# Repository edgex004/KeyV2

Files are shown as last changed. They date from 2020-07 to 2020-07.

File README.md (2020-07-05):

Note: this branch contains modifications in order to generate LP (Choc) keycaps for the Lily58 keyboard.

# Parametric Mechanical Keycap Library

a slightly askew welcome picture

This library is a keycap and keyset construction library for mechanical keyboards, written in openSCAD.

Relevant links:
* Thingiverse: https://www.thingiverse.com/thing:2783650
* Shapeways: https://www.shapeways.com/designer/rsheldiii/creations
* Buy me a coffee: https://ko-fi.com/rsheldiii, but only if you want to!

## How to run

#### OpenSCAD Proper (recommended way)

If you are technically inclined at all, this is definitely the best way to run the code. It's not very hard!

First, you'll need OpenSCAD: http://www.openscad.org/downloads.html. I highly recommend installing the development snapshot, as they generally support more features and are relatively stable. Development snapshots are listed in their own section on the downloads page.

After you have openSCAD installed, you need to download the code and run it. running `git clone https://github.com/rsheldiii/openSCAD-projects.git` if you have git, or downloading [this zip](https://github.com/rsheldiii/openSCAD-projects/archive/master.zip) and extracting the directory should do it. Then all you need to do is open `keys.scad` with openSCAD and you are set! It is possible to edit this project with an external editor by checking off Design => 'Automatic Reload and Preview' in OpenSCAD.

All examples below assume you are running the library on your computer with OpenSCAD.

#### OpenSCAD Customizer

If you're not technically inclined enough to start programming in OpenSCAD (it's easier than you think), you can look into [getting OpenSCAD's customizer working](https://github.com/rsheldiii/KeyV2/wiki/Getting-the-OpenSCAD-Customizer-working).

`customizer.scad` is auto-generated from the other files in this repository due to a quirk with how OpenSCAD shows customizer settings. It should be perpetually kept up to date, but there may be some bugs. feel free to open an issue if you find one!

#### Thingiverse Customizer

The easiest and buggiest way to run this program is to boot it up in [Thingiverse's Customizer](https://www.thingiverse.com/apps/customizer/run?thing_id=2783650). Explanations of each option are provided, as well as some default variables. Twiddle the variables to see how the keycap changes!

Unfortunately I don't think I can update the Thingiverse customizer without breaking it, so you don't get all the cool new features I've been developing over the past couple years.

## High-level overview

This library supports Cherry and Alps switches, and has pre-defined key profiles for SA, DSA, DCS, G20, Hi-Pro and (some form of) OEM keycaps. `keys.scad` is the entry point for everything but the most technical use. Pre-programmed key profiles can be found in the `key_profiles` directory.

Every key starts with default settings (provided in `settings.scad`) that are overridden by each function call. The simplest key you can make would be:

```
key();
```
a bog-standard cherry key

which is a bog-standard DCS row 5 (number / function row) keycap. To change how the key is generated, you can modify the settings directly or add predefined modifier functions like so:

```
// directly modified setting
$stem_inset = 1;
// settings changed through modifier function
sa_row(2) 2u() key();
```

You can chain as many modifier functions as you like!

a 2 unit SA row 2 cherry key

## Modifier functions

There is a bevy of supporting functions to customize your keycaps. You can add a brim to more easily print the stem with `brimmed_stem_support`, make 2x2 keycaps with `2u() 2uh()`, add legends, rotate stems, and more. All these functions manipulate the settings available to you in [`settings.scad`](https://github.com/rsheldiii/KeyV2/blob/master/src/settings.scad), though [some of them](https://github.com/rsheldiii/KeyV2/blob/master/src/key_transformations.scad#L128) are quite complex.

These modifier functions can be found in [`key_profiles/`](https://github.com/rsheldiii/KeyV2/blob/master/src/key_profiles) for different keycap profiles, [`key_types.scad`](https://github.com/rsheldiii/KeyV2/blob/master/src/key_types.scad) for predefined settings for common keys (spacebar, left shift, etc), [`key_sizes.scad`](https://github.com/rsheldiii/KeyV2/blob/master/src/key_sizes.scad) for common unit sizes, and [`key_transformations.scad`](https://github.com/rsheldiii/KeyV2/blob/master/src/key_transformations.scad) for everything else. I encourage you to do some sleuthing but for a list of (most) helper functions with explanations, [Check out the wiki!](https://github.com/rsheldiii/KeyV2/wiki/KeyV2-Helper-Documentation)

These modifier functions may not cover every use case; in that case, you may have to write some SCAD yourself.

## Layouts

new to the library and still in a beta state, layouts allows you to generate an entire layout for a keyboard!

It is recommended to use tined stem support and set `$extra_long_stem_support = true` if you plan on printing these keycaps.

```
60_percent_default("dcs") key();
```

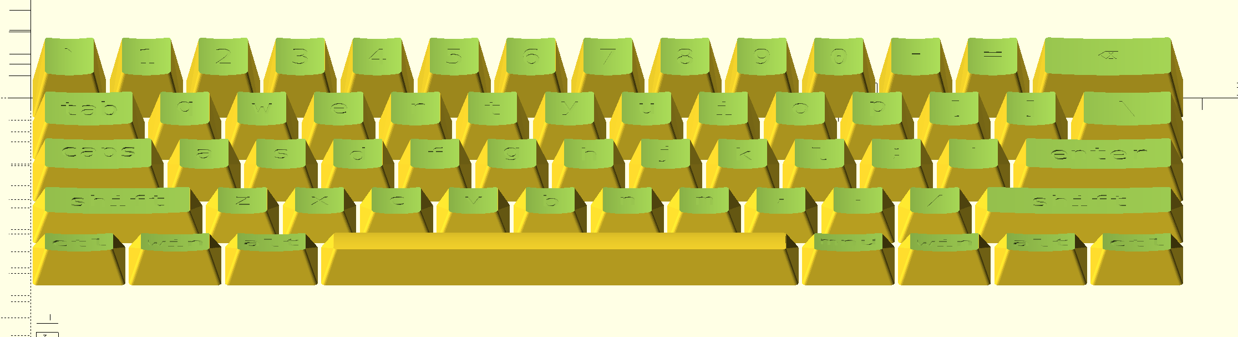
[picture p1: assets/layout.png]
a standard 60 percent layout


layouts accept children, so you can use them as a chained function like other modifiers. Be wary of accidentally overriding something the layout does for you though.

#### Example customizations

Let's say you wanted to generate some 2u stabilized keycaps for an Ergodox, you could do something like this:

```
legends = ["Enter", "Escape", "Tab", "Shift"];
for(y=[0:3]) {
  translate_u(0,y) 2u() dsa_row() stabilized() cherry() legend(legends[y], [0,0, 6]) key();
}
```

a set of 2 unit keys with legends

The `key()` function also supports children, and will place them in the center of the top of the keycap, if you want to quickly design your own artisan keycaps:

```
cherry() key() {
  translate([-6.25,2.3,-0]) scale(0.074) import("Assieme1.stl");
};
```

an artisan key with no-face on it

(no face courtesy of [this thing](https://www.thingiverse.com/thing:519727/))

Artisan support also supports _subtracting_ children by doing `key(inset=true) { ... }`, which is super helpful if you want to make keycaps with legends that are not text. The children will be placed just above the middle of the dish as per usual; you will need to translate them downwards (`ex translate([0,0,-1])`) to get them to 'dig in' to the top of the key.

## Tips and tricks

Looking for information or something specific? you could try checking out the [tips and tricks](TIPS_AND_TRICKS.md) section, or the [examples](/examples) directory.

## What if I want to get _really_ technical?

Now we're talkin!

At the base level this project should function well as an intensive key profile design library. by loading up `src/key.scad` (notice no s) you can tweak variables in `src/settings.scad` to prototype your own profiles. `key.scad` There are currently ~~44~~ a lot of different settings to tweak in `src/settings.scad` including width height and depth of the keycap, dish tilt, top skew, fonts, wall thickness, etc. If you want to see the full list of settings, feel free to browse the file itself: [settings.scad](https://github.com/rsheldiii/KeyV2/blob/master/src/settings.scad) it has lots of comments to help you get started.

This library should also be abstract enough to handle new dish types, keystems, key layouts, key profiles, and key shapes, in case you want to design your own Typewriter-style keycaps, support buckling spring keyboards or design some kind of triangular dished profile. `src/shapes.scad` `src/stems.scad` and `src/dishes.scad` all have a 'selector' module that should allow you to implement your own creations alongside what already exists in their constituent folders.

If you're interested in this, it may help to read the [Technical Design of a keycap](https://github.com/rsheldiii/KeyV2/wiki/Technical-Design-of-a-Keycap) wiki page.

Here's an example of tweaking the settings and code to make a 'stop sign' key profile:

In `key_shape()` in `shapes.scad`:

```
 else if ($key_shape_type == "stop_sign") {
   stop_sign_shape(size, delta, progress);
 }
```

in `src/shapes/stop_sign.scad`:

```
module stop_sign_shape(size, delta, progress){
  rotate([0,0,22.5]) circle(d=size[0] - delta[0], $fn=8);
}
```

In `keys.scad`:

```
union() {
  // make the font smaller
  $font_size = 3;
  // top of keycap is the same size as the bottom
  $width_difference = 0;
  $height_difference = 0;
  $key_shape_type="stop_sign";
  $dish_type = "cylindrical";
  // some keycap tops are slid backwards a little, and we don't want that
  $top_skew = 0;

  legends = ["Stop..", "Hammer", "time!"];

  for(x=[0:len(legends)-1]) {
    translate_u(x) cherry() key(legends[x]);
  }
}
```

three stop-sign shaped keys with legends

## Printing Help

Prints from this library are still challenging, despite all efforts to the contrary. Resin printers can create great looking keycaps; FDM printers can create usable keys that look alright, but may require tweaking to get prints acceptable. There are a few quick things that you can do:

1. If your stem isn't fitting in the switch, try upping the slop factor, accessed by giving your keystem function a numeric value (eg `cherry(0.5) key()`). This will lengthen the cross and decrease the overall size of the keystem. The default value is 0.3, and represents millimeters. Note that even if you have a resin printer, you should probably keep the default value; keys printed with 0 slop will barely fit on the stem.

2. If your keystem breaks off the bed mid-print, you can enable a brim by adding the `brimmed()` modifier. This will give a solid base for the keystem to anchor into.

3. If you are unsatisfied with the quality of the top surface, you can try printing the keycap on a different surface than the bottom, though it may impact the quality of the stem.

4. If your newly-designed key shape is crashing into the switch, you can enable a clearance check for cherry switches by adding `$clearance_check = true;` to your keycap declaration. This will subtract a cherry switch shape from your keycap, highlighting any parts in red which intersect with the switch.

That's it, if you have any questions feel free to open an issue or leave a comment on thingiverse!

## TODO:
 * replace linear_extrude_shape_hull with skin_extrude_shape_hull or something, to enable concave extrusions
 * replace current ISO enter shape with one that works for `skin()`
 * generate dishes via math?

## Contributions welcome

 My lists of key profiles and layouts are not exhaustive at all, if you want to contribute feel free to make a PR with your changes and we can work together on getting it merged!

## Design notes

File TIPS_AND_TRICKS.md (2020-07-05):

# WIP Tips and Tricks section

just want to make sure I put this here, I'm going to make this a much better document later

## Fully sculpted caps

Fully sculpted keycaps are caps that also tilt inwards / outwards, cupping your fingers a bit.

Most profiles should support this now; you pass in a "column" value after the row value, and the cap will calculate how much extra height and tilt for that column.

the way this works is the program projects a large, imaginary cylinder that it inscribes the top of the keycaps into. Thus, the height and tilt can be tweaked by changing the `$double_sculpt_radius`, which changes the radius of that imaginary cylinder.

At the end of the day though, all the columnular sculpting is doing is adding extra height and y tilt to the top of the key. if you have some other aim than fitting to a cylinder you can control this directly with appropriate changes to `$top_tilt_y` and `$total_depth`, or perhaps changing the `side_tilt()` and `extra_side_tilt_height()` functions in [`functions.scad`](https://github.com/rsheldiii/KeyV2/blob/master/src/functions.scad) which are what the row profiles use.

## skin mode

SA, HiPro and DSA keycaps take _forever_ to render. This is a multifaceted issue that I don't want to get into here, but suffice to say _one_ of the reasons it takes so long is how the keycap is constructed from multiple, smaller slices. OpenSCAD takes more time to render the more objects you have, regardless of how they interact. Enter `$skin_extrude_shape = true`.

`skin()` is a list comprehension function available [here](https://github.com/openscad/list-comprehension-demos/blob/master/skin.scad). The gist of it is that instead of having x number of keycap slices unioned together, we give `skin()` a set of profiles and it makes a single object out of it for us. This reduces the number of objects per keycap, which makes it easier to render them.

One current limitation of `skin()` is that I suck at math and can't translate [rounded_square](https://github.com/rsheldiii/KeyV2/blob/master/src/shapes/rounded_square.scad) into a function, which means that we miss out on the very nice bowing exhibited on these profiles. once we can translate that to math however, we'll be in business.

## Printing upside down

still in beta, but using `upside_down()` in a method chain will rotate keycaps to be upside down. This makes the stem print better and requires no support, but generally the top of the keycap comes out worse - unless it is flat. Worth noting that you can probably set `$stem_inner_slop` to 0 if you print upside down - elephant's foot is the largest contributor to stems not fitting correctly.

### "doubleshot" letters with a regular printer

While printing upside down, you can do yourself a favor and embed some legends! use code like below:

```
legends = ["F1", "1", "q", "a", "z", ""];
for (x = [0:1:4]) {
  translate_u(0,-x) legend(legends[x]) g20_row(3, 0) upside_down() {
      $stem_support_type = "disable";
      key(true);
      dished() {
        legends($inset_legend_depth);
      }
  }
}
```

and comment out either `key(true)` or the whole `dished` segment. This code generates keycaps with inset legends and the legends that fit inside those insets.

Run just the legends through your slicer first and make sure to turn off anything like skirts or brims, it should print your legends in a single layer on your print bed. Leave them there, swap filaments, and then print the rest of the keycaps around them in a different color. The result is pretty impressive. They aren't quite doubleshot, since the main benefit of doubleshots is the plastic goes all the way through the keycap, but they look incredibly impressive for what they are.

### No stem support

If you're printing updside down you'll want to disable stem supports. you can change the `$stem_support_type`, or just use the `no_stem_support()` modifier function

## front print legends and location / font size

still in beta, set `$front_print_legends = true` to have legends print on the front instead of the top of the keycaps.   

## Clearance check

doing some funky stuff and want to make sure your keycap won't hit the keyswitch? set `$clearance_check = true` and a red-colored depressed switch will show up in preview, cutting away at what contacts the switch.

## Envelope

the 'envelope' of a keycap is used to clip geometry - most notably the dishing at the top of the keycap. if something doesn't look right, you can drop `%envelope()` right next to `key()` to see if it's the envelope cutting things off:

```
g20_row() legend("Q", [0,0], 3) {
   key();
   %envelope();
 }
```

## stem inset

If you want the more refined top surface that printing upright brings, but you are having a bad time with elephant's foot, you can enable some `$stem_inset` and see if that helps. you'll have to figure out what support works best for you.

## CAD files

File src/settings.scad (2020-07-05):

/* [Basic-Settings] */

// Length in units of key. A regular key is 1 unit; spacebar is usually 6.25
$key_length = 1.0; // Range not working in thingiverse customizer atm [1:0.25:16]

// What type of stem you want. Most people want Cherry.
$stem_type = "cherry";  // [cherry, alps, rounded_cherry, box_cherry, filled, disable]

// The stem is the hardest part to print, so this variable controls how much 'slop' there is in the stem
// if your keycaps stick in the switch raise this value
$stem_slop = 0.35; // Not working in thingiverse customizer atm [0:0.01:1]
// broke this out. if your keycaps are falling off lower this value. only works for cherry stems rn
$stem_inner_slop = 0.2;

// Font size used for text
$font_size = 6;

// Set this to true if you're making a spacebar!
$inverted_dish = false;

// change aggressiveness of double sculpting
// this is the radius of the cylinder the keytops are placed on
$double_sculpt_radius = 200;


// Support type. default is "flared" for easy FDM printing; bars are more realistic, and flat could be for artisans
$support_type = "flared"; // [flared, bars, flat, disable]

// Supports for the stem, as it often comes off during printing. Reccommended for most machines
$stem_support_type = "tines"; // [tines, brim, disabled]

// make legends outset instead of inset.
// broken off from artisan support since who wants outset legends?
$outset_legends = false;

/* [Key] */
// Height in units of key. should remain 1 for most uses
$key_height = 1.0;
// Keytop thickness, aka how many millimeters between the inside and outside of the top surface of the key
$keytop_thickness = 1;
// Wall thickness, aka the thickness of the sides of the keycap. note this is the total thickness, aka 3 = 1.5mm walls
$wall_thickness = 3;
// Radius of corners of keycap
$corner_radius = 1;
// Width of the very bottom of the key
$bottom_key_width = 18.16;
// Height (from the front) of the very bottom of the key
$bottom_key_height = 18.16;
// How much less width there is on the top. eg top_key_width = bottom_key_width - width_difference
$width_difference = 6;
// How much less height there is on the top
$height_difference = 4;
// How deep the key is, before adding a dish
$total_depth = 11.5;
// The tilt of the dish in degrees. divided by key height
$top_tilt = -6;
// the y tilt of the dish in degrees. divided by key width.
// for double axis sculpted keycaps and probably not much else
$top_tilt_y = 0;
// How skewed towards the back the top is (0 for center)
$top_skew = 1.7;

// how skewed towards the right the top is. unused, but implemented.
// for double axis sculpted keycaps and probably not much else
$top_skew_x = 0;

/* [Stem] */

// How far the throw distance of the switch is. determines how far the 'cross' in the cherry switch digs into the stem, and how long the keystem needs to be before supports can start. luckily, alps and cherries have a pretty similar throw. can modify to have stouter keycaps for low profile switches, etc
$stem_throw = 4;
// Diameter of the outside of the rounded cherry stem
$rounded_cherry_stem_d = 5.5;


// How much higher the stem is than the bottom of the keycap.
// Inset stem requires support but is more accurate in some profiles
$stem_inset = 0;
// How many degrees to rotate the stems. useful for sideways keycaps, maybe
$stem_rotation = 0;

// enable to have stem support extend past the keycap bottom, to (hopefully) the next
// keycap. only works on tines right now
$extra_long_stem_support = false;

/* [Shape] */

// Key shape type, determines the shape of the key. default is 'rounded square'
$key_shape_type = "rounded_square";
// ISO enter needs to be linear extruded NOT from the center. this tells the program how far up 'not from the center' is
$linear_extrude_height_adjustment = 0;
// How many slices will be made, to approximate curves on corners. Leave at 1 if you are not curving corners
// If you're doing fancy bowed keycap sides, this controls how many slices you take
$height_slices = 1;

/* [Dish] */

// What type of dish the key has. note that unlike stems and supports a dish ALWAYS gets rendered.
$dish_type = "cylindrical"; // [cylindrical, spherical, sideways cylindrical, old spherical, disable]
// How deep the dish 'digs' into the top of the keycap. this is max depth, so you can't find the height from total_depth - dish_depth. besides the top is skewed anyways
$dish_depth = 1;
// How skewed in the x direction the dish is
$dish_skew_x = 0;
// How skewed in the y direction (height) the dish is
$dish_skew_y = 0;
// If you need the dish to extend further, you can 'overdraw' the rectangle it will hit
$dish_overdraw_width = 0;
// Same as width but for height
$dish_overdraw_height = 0;

/* [Misc] */
// There's a bevel on the cherry stems to aid insertion / guard against first layer squishing making a hard-to-fit stem.
$cherry_bevel = true;

// How tall in mm the stem support is, if there is any. stem support sits around the keystem and helps to secure it while printing.
$stem_support_height = .8;
// Font used for text
$font="DejaVu Sans Mono:style=Book";
// Whether or not to render fake keyswitches to check clearances
$clearance_check = false;
// Should be faster, also required for concave shapes
// Use linear_extrude instead of hull slices to make the shape of the key
$linear_extrude_shape = false;

// warns in trajectory.scad but it looks benign
// brand new, more correct, hopefully faster, lots more work
$skin_extrude_shape = false;
// This doesn't work very well, but you can try
$rounded_key = false;
//minkowski radius. radius of sphere used in minkowski sum for minkowski_key function. 1.75 for G20
$minkowski_radius = .33;

/* [Features] */

//insert locating bump
$key_bump = false;
//height of the location bump from the top surface of the key
$key_bump_depth = 0.5;
//distance to move the bump from the front edge of the key
$key_bump_edge = 0.4;

/* [Hidden] */

// set this to true if you are making double sculpted keycaps
$double_sculpted = false;

//list of legends to place on a key format: [text, halign, valign, size]
//halign = "left" or "center" or "right"
//valign = "top" or "center" or "bottom"
// Currently does not work with thingiverse customizer, and actually breaks it
$legends = [];

//list of front legends to place on a key format: [text, halign, valign, size]
//halign = "left" or "center" or "right"
//valign = "top" or "center" or "bottom"
// Currently does not work with thingiverse customizer, and actually breaks it
$front_legends = [];

// print legends on the front of the key instead of the top
$front_print_legends = false;

// how recessed inset legends / artisans are from the top of the key
$inset_legend_depth = 0.2;

// Dimensions of alps stem
$alps_stem = [4.45, 2.25];

// Dimensions of choc stem
$choc_stem = [1.2, 3];

// Enable stabilizer stems, to hold onto your cherry or costar stabilizers
$stabilizer_type = "costar_stabilizer"; // [costar_stabilizer, cherry_stabilizer, disable]

// Ternaries are ONLY for customizer. they will NOT work if you're using this in
// OpenSCAD. you should use stabilized(), openSCAD customizer,
// or set $stabilizers directly
// Array of positions of stabilizers
$stabilizers = $key_length >= 6 ? [[-50, 0], [50, 0]] : $key_length >= 2 ? [[-12,0],[12,0]] : [];

// Where the stems are in relation to the center of the keycap, in units. default is one in the center
// Shouldn't work in thingiverse customizer, though it has been...
$stem_positions = [[0,0]];

// colors
$primary_color = [.2667,.5882,1];
$secondary_color = [.4412, .7, .3784];
$tertiary_color = [1, .6941, .2];
$quaternary_color = [.4078, .3569, .749];
$warning_color = [1,0,0, 0.15];

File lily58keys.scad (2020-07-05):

// the point of this file is to be a sort of DSL for constructing keycaps.
// when you create a method chain you are just changing the parameters
// key.scad uses, it doesn't generate anything itself until the end. This
// lets it remain easy to use key.scad like before (except without key profiles)
// without having to rely on this file. Unfortunately that means setting tons of
// special variables, but that's a limitation of SCAD we have to work around

use <src/key.scad>

include <src/settings.scad>
include <src/key_sizes.scad>
include <src/key_profiles.scad>
include <src/key_types.scad>
include <src/key_transformations.scad>
include <src/key_helpers.scad>

    $double_sculpt_radius =1000;


module lilykey(row,col,width=1){
  $key_bump = (row ==2 && (col == 1 || col==4) );
  $stem_support_height = .5;

  u(width) choc(.1) flared_support()  tined_stem_support() low_profile()
    loprolilly_row(row,col) key();
}

module thumb_skinny(){
lilykey(0,-1);
}

module thumb_square() {
    lilykey(0,0);

}
   
module row2() {
        lilykey(2,0);
}

module row1() {
    lilykey(1,0);
}

// module layer_key() {
//     lilykey(0,0);
// }

module num_key() {
    lilykey(5,0);
}

module bump_key() {
    lilykey(2,1);

}
module escape() {
     $double_sculpted= true;

    lilykey(5,5);

}
module col5() {
   $double_sculpted= true;

    lilykey(1,5);

}
module test_print () {
  lilykey(0,-1);
  translate([20,0,0]) 
    lilykey(5,0);
  translate([40,0,0]) 
    lilykey(2,1);
  translate([60,0,0]) 
  {
    $double_sculpted= true;
    $double_sculpted_hack = true;
    lilykey(5,5);
  }
  for ( i = [0 : 2] ){
    translate([80+20*i,0,0]) 
      lilykey(i,0);
  }
}

module test_double_skulpt () {
  escape();
  for ( i = [0 : 3] ){
    translate([20+20*i,0,0]) 
      col5();
  }
  for ( i = [0 : 5] ){
    translate([20*i,20,0]) 
      num_key();
  }
}

module full_layout () {

    translate([20,5,0]) 
      thumb_skinny();
    translate([20,35,0]) 
      thumb_skinny();

    translate([20,60,0]) 
    row2();

    translate([20,80,0]) 
num_key();

    translate([120,0,0]) 
    row2();

    translate([140,0,0]) 
    row1();

//  translate([40,-40,0]) 

for ( i = [0 : 3] ){
  translate([40+20*i,0,0]) 
    thumb_square();
}

//  translate([40,0,0]) 
//    layer_key();

// for ( i = [0 : 4] ){
//  translate([40+20*i,20,0]) 
//    row1();
// }

  translate([40+0,20,0]) 
    row1();

  translate([40+20,20,0]) 
    row1();

  translate([40+40,20,0]) 
    row1();
  translate([40+60,20,0]) 
    row1();
  translate([40+80,20,0]) 
    row1();
for (j=[0:1]){
for ( i = [0 : 4] ){
    
    if(j==0 && (i==1 || i==4)){
  translate([40+20*i,40+20*j,0]) 
    bump_key();
    }else{
          translate([40+20*i,40+20*j,0]) 
    row2();
    }
}
}

for ( i = [0 : 4] ){
  translate([40+20*i,80,0]) 
    num_key();
}

for ( i = [0 :2] ){
  translate([140,20+20*i ,0]) 
    col5();
}

for ( i = [0 :3] ){
  translate([140,80 ,0]) 
    escape();
}
}
  // {
  //   $double_sculpted_hack = true;
  //   $double_sculpt_radius =1000;
  //   lilykey(5,5);
  // }
// test_print();
test_double_skulpt();
//  full_layout();

// translate ([20,0,0]) lilykey(2,1,1);
// lilykey(1,0,1);

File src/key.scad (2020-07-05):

// files
include <functions.scad>
include <shapes.scad>
include <stems.scad>
include <stem_supports.scad>
include <dishes.scad>
include <supports.scad>
include <key_features.scad>

include <libraries/geodesic_sphere.scad>

// for skin hulls
use <libraries/scad-utils/transformations.scad>
use <libraries/scad-utils/lists.scad>
use <libraries/scad-utils/shapes.scad>
use <libraries/skin.scad>


/* [Hidden] */
SMALLEST_POSSIBLE = 1/128;
$fs = .1;
$unit = 19.05;

// key shape including dish. used as the ouside and inside shape in keytop(). allows for itself to be shrunk in depth and width / height
module shape(thickness_difference, depth_difference=0){
  dished(depth_difference, $inverted_dish) {
    color($primary_color) shape_hull(thickness_difference, depth_difference, $inverted_dish ? 2 : 0);
  }
}

// shape of the key but with soft, rounded edges. no longer includes dish
// randomly doesnt work sometimes
// the dish doesn't _quite_ reach as far as it should
module rounded_shape() {
  dished(-$minkowski_radius, $inverted_dish) {
    color($primary_color) minkowski(){
      // half minkowski in the z direction
      color($primary_color) shape_hull($minkowski_radius * 2, $minkowski_radius/2, $inverted_dish ? 2 : 0);
      /* cube($minkowski_radius); */
      sphere(r=$minkowski_radius, $fn=48);
    }
  }
  /* %envelope(); */
}

// this function is more correct, but takes _forever_
// the main difference is minkowski happens after dishing, meaning the dish is
// also minkowski'd
/* module rounded_shape() {
  color($primary_color) minkowski(){
    // half minkowski in the z direction
    shape($minkowski_radius * 2, $minkowski_radius/2);
    difference(){
      sphere(r=$minkowski_radius, $fn=20);
      translate([0,0,-$minkowski_radius]){
        cube($minkowski_radius * 2, center=true);
      }
    }
  }
} */



// basic key shape, no dish, no inside
// which is only used for dishing to cut the dish off correctly
// $height_difference used for keytop thickness
// extra_slices is a hack to make inverted dishes still work
module shape_hull(thickness_difference, depth_difference, extra_slices = 0){
  render() {
    if ($skin_extrude_shape) {
      skin_extrude_shape_hull(thickness_difference, depth_difference, extra_slices);
    } else if ($linear_extrude_shape) {
      linear_extrude_shape_hull(thickness_difference, depth_difference, extra_slices);
    } else {
      hull_shape_hull(thickness_difference, depth_difference, extra_slices);
    }
  }
}

// use skin() instead of successive hulls. much more correct, and looks faster
// too, in most cases. successive hull relies on overlapping faces which are
// not good. But, skin works on vertex sets instead of shapes, which makes it
// a lot more difficult to use
module skin_extrude_shape_hull(thickness_difference, depth_difference, extra_slices = 0 ) {
  skin([
    for (index = [0:$height_slices + extra_slices])
      let(
        progress = (index / $height_slices),
        skew_this_slice = $top_skew * progress,
        x_skew_this_slice = $top_skew_x * progress,
        depth_this_slice = ($total_depth - depth_difference) * progress,
        tilt_this_slice = -$top_tilt / $key_height * progress,
        y_tilt_this_slice = $double_sculpted ? (-$top_tilt_y / $key_length * progress) : 0
      )
      skin_shape_slice(progress, thickness_difference, skew_this_slice, x_skew_this_slice, depth_this_slice, tilt_this_slice, y_tilt_this_slice)
  ]);
}

function skin_shape_slice(progress, thickness_difference, skew_this_slice, x_skew_this_slice, depth_this_slice, tilt_this_slice, y_tilt_this_slice) =
  transform(
    translation([x_skew_this_slice,skew_this_slice,depth_this_slice]),
    transform(
      rotation([tilt_this_slice,y_tilt_this_slice,0]),
        skin_key_shape([
          total_key_width(0),
          total_key_height(0),
          ],
          [$width_difference, $height_difference],
          progress,
          thickness_difference
        )
    )
  );

// corollary is hull_shape_hull
// extra_slices unused, only to match argument signatures
module linear_extrude_shape_hull(thickness_difference, depth_difference, extra_slices = 0){
  height = $total_depth - depth_difference;
  width_scale = top_total_key_width() / total_key_width();
  height_scale = top_total_key_height() / total_key_height();

  translate([0,$linear_extrude_height_adjustment,0]){
    linear_extrude(height = height, scale = [width_scale, height_scale]) {
        translate([0,-$linear_extrude_height_adjustment,0]){
        key_shape(
          [total_key_width(thickness_difference), total_key_height(thickness_difference)],
          [$width_difference, $height_difference]
        );
      }
    }
  }
}

module hull_shape_hull(thickness_difference, depth_difference, extra_slices = 0) {
  for (index = [0:$height_slices - 1 + extra_slices]) {
    hull() {
      shape_slice(index / $height_slices, thickness_difference, depth_difference);
      shape_slice((index + 1) / $height_slices, thickness_difference, depth_difference);
    }
  }
}

module shape_slice(progress, thickness_difference, depth_difference) {
  skew_this_slice = $top_skew * progress;
  x_skew_this_slice = $top_skew_x * progress;

  depth_this_slice = ($total_depth - depth_difference) * progress;

  tilt_this_slice = -$top_tilt / $key_height * progress;
  y_tilt_this_slice = $double_sculpted ? (-$top_tilt_y / $key_length * progress) : 0;

  translate([x_skew_this_slice, skew_this_slice, depth_this_slice]) {
    rotate([tilt_this_slice,y_tilt_this_slice,0]){
      linear_extrude(height = SMALLEST_POSSIBLE){
        key_shape(
          [
            total_key_width(thickness_difference),
            total_key_height(thickness_difference)
          ],
          [$width_difference, $height_difference],
          progress
        );
      }
    }
  }
}

// for when you want something to only exist inside the keycap.
// used for the support structure
module inside() {
  intersection() {
    shape($wall_thickness, $keytop_thickness);
    children();
  }
}

// put something at the top of the key, with no adjustments for dishing
module top_placement(depth_difference=0) {
  top_tilt_by_height = -$top_tilt / $key_height;
  top_tilt_y_by_length = $double_sculpted ? (-$top_tilt_y / $key_length) : 0;

  minkowski_height = $rounded_key ? $minkowski_radius : 0;

  translate([$top_skew_x + $dish_skew_x, $top_skew + $dish_skew_y, $total_depth - depth_difference + minkowski_height/2]){
    rotate([top_tilt_by_height, top_tilt_y_by_length,0]){
      children();
    }
  }
}

module front_placement() {
  // all this math is to take top skew and tilt into account
  // we need to find the new effective height and depth of the top, front lip
  // of the keycap to find the angle so we can rotate things correctly into place
  total_depth_difference = sin(-$top_tilt) * (top_total_key_height()/2);
  total_height_difference = $top_skew + (1 - cos(-$top_tilt)) * (top_total_key_height()/2);

  angle = atan2(($total_depth - total_depth_difference), ($height_difference/2 + total_height_difference));
  hypotenuse = ($total_depth -total_depth_difference) / sin(angle);

  translate([0,-total_key_height()/2,0]) {
    rotate([-(90-angle), 0, 0]) {
      translate([0,0,hypotenuse/2]){
        children();
      }
    }
  }
}

// just to DRY up the code
module _dish() {
  color($secondary_color) dish(top_total_key_width() + $dish_overdraw_width, top_total_key_height() + $dish_overdraw_height, $dish_depth, $inverted_dish);
}

module envelope(depth_difference=0) {
  s = 1.5;
  hull(){
    cube([total_key_width() * s, total_key_height() * s, 0.01], center = true);
    top_placement(SMALLEST_POSSIBLE + depth_difference){
      cube([top_total_key_width() * s, top_total_key_height() * s, 0.01], center = true);
    }
  }
}

// I think this is unused
module dished_for_show() {
  difference(){
    union() {
      envelope();
      if ($inverted_dish) top_placement(0) _dish();
    }
    if (!$inverted_dish) top_placement(0) _dish();
  }
}


// for when you want to take the dish out of things
// used for adding the dish to the key shape and making sure stems don't stick out the top
// creates a bounding box 1.5 times larger in width and height than the keycap.
module dished(depth_difference = 0, inverted = false) {
  intersection() {
    children();
    difference(){
      union() {
        envelope(depth_difference);
        if (inverted) top_placement(depth_difference) _dish();
      }
      if (!inverted) top_placement(depth_difference) _dish();
    }
  }
}
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

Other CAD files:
src/key_profiles.scad
examples/legends.scad
examples/multimaterial_key_top.scad
examples/multimaterial_legend.scad
examples/plate_generation.scad
examples/print_keycaps_on_their_side.scad
examples/sa_ergo.scad
examples/single_extruder_multimaterial_legends.scad
includes.scad
src/dishes.scad
src/dishes/flat.scad
src/dishes/spherical.scad
src/functions.scad
src/key_layouts.scad
src/key_profiles/dcs.scad
src/key_profiles/dsa.scad
src/key_profiles/grid.scad
src/key_profiles/hipro.scad
src/key_profiles/loprolilly.scad
src/key_profiles/oem.scad
src/key_profiles/sa.scad
src/key_transformations.scad
src/key_types.scad
src/layouts/60_percent/default.scad
src/layouts/dactyl_manuform/4x6.scad
src/layouts/dactyl_manuform/4x6_legends.scad
src/layouts/gherkin/default.scad
src/layouts/gherkin/gherkin_bump.scad
src/layouts/layout.scad
src/layouts/lets_split/default.scad
src/layouts/planck/default.scad
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
